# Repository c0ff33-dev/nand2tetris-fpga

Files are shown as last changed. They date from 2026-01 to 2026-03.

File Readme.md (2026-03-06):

# nand2tetris-fpga (v4.0.1)

## Disclaimer

This is both a complete implementation & fork of Michael Schröder's [course](https://gitlab.com/x653/nand2tetris-fpga). I have made my own revisions, extensions and corrections to:

* Update the code for modern tooling.
* Update virtually all of the documentation for readability, accuracy & completeness.
* Update the architecture to support current hardware revisions of the relevant boards.
* Restore ABI/API compatibility with VGA & PS/2 support in the [classic](./09_More_Fun_to_Go/) HACK implementation.
* Replace the original tools with a more sophisticated & optimized Jack compiler toolchain.

Please see [Changelog.md](./Changelog.md) for details.

***

> _Wouldn't it be nice to make Hack or Jack also run on some "real platform" made from some "real stuff"?_
> 
> Noam Nisan and Shimon Schocken

This project is about building HACK on real hardware as proposed in Chapter 13 of the course [nand2tetris](https://www.nand2tetris.org/) using only FOSS, free and open source hardware and software.

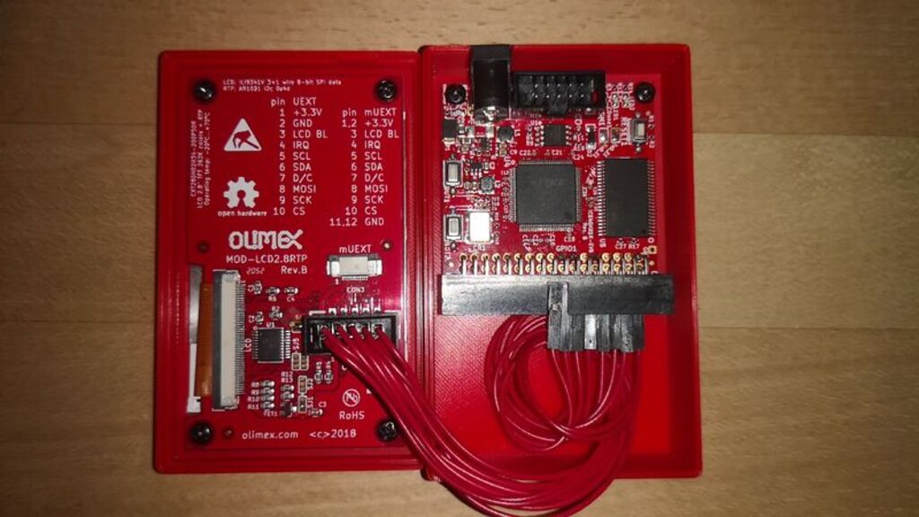
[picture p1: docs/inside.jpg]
 

Our final implementation of `HACK` will have the following specs:

* Original CPU/ALU design of `HACK` from nand2tetris.

* Implemented on `iCE40HX1K-EVB` from Olimex.

* Clocked at 25 MHz.

* BRAM 3584 x 16 bit (R0-R15/static/stack/heap).

* SRAM 64K x 16 bit (instruction memory).

* Bootloader boots `HACK` code from flash ROM into SRAM.

* 2.8 inch color `LCD` with 320x240 pixel.

* Resistive Touch Panel (`RTP`) support.

* Powerful enough to run Tetris!
  
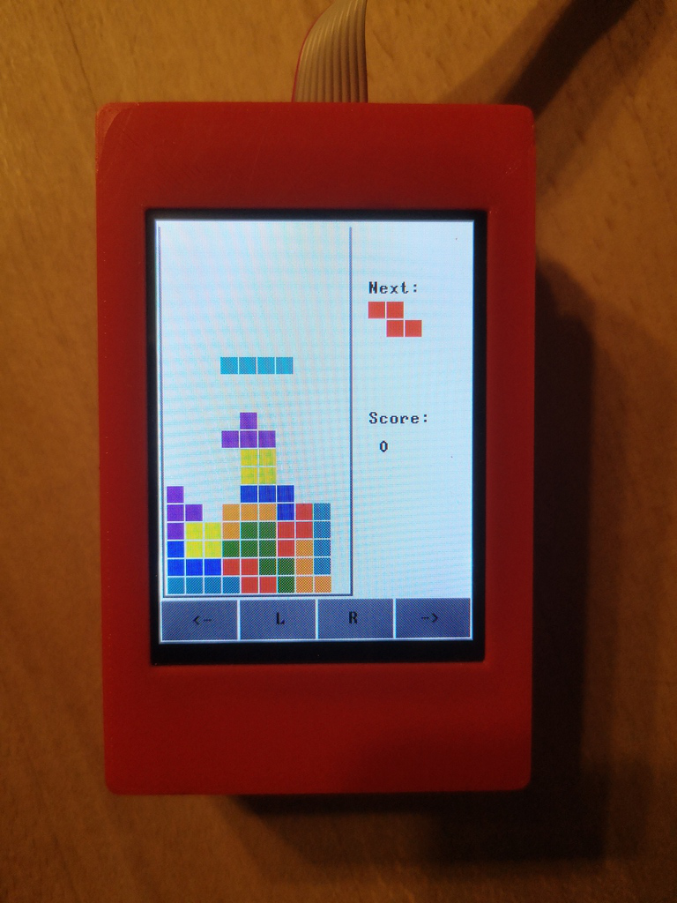
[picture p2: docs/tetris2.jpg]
  

***

## Roadmap

In every project folder you find a file `Readme.md` containing specifications and implementation details.

> _This is your last chance. After this, there is no turning back. You take the blue pill - the story ends, you wake up in your bed and believe whatever you want to believe. You take the red pill - you stay in Wonderland and I show you how deep the rabbit-hole goes._
> 
> Morpheus

### [00 Prerequisites](00_Prerequisites)

Get the hardware and install the tools.

### [01 Boolean Logic](01_Boolean_Logic)

Start with a simple `Nand` gate and build the logic chips: `Not`, `Buffer`, `And`, `Or`, `Xor`, `Mux`, `DMux`, and their multi-bit versions `Not16`, `Buffer16`, `And16`, `Or16`, `Mux16`, `Or8Way`, `Mux4Way16`, `Mux8Way16`, `DMux4Way` and `DMux8Way`.

### [02 Boolean Arithmetic](02_Boolean_Arithmetic)

Implement `HalfAdder`, `FullAdder`, `Add16`, `Inc16` and the `ALU`.

### [03 Sequential Logic](03_Sequential_Logic)

Build sequential chips `Bit` , `Register` and `PC` that make use of the Data Flip Flop (`DFF`) to store the state. `DFF` is a Verilog primitive so it will not necessary to implement it. The memory chips `RAM512` and `RAM3584` are based on the BRAM primitive `RAM256`, which uses Block RAM (BRAM) structures integrated in `iCE40HX1K`. `BitShift9R` and `BitShift8L` are new chips not explained in the original nand2tetris course. They serve to connect `HACK` to different I/O devices which are connected using a serial protocol where data is transmitted bitwise.

### [04 Machine Language](04_Machine_Language)

Write two little machine language programms to run on `HACK`. The first program `leds.asm` will test I/O capability of `HACK`. Every time the user presses the buttons `BUT1/2` on the `iCE40HX1K-EVB` board  the `LED` will change accordingly. With the second program `mult.asm` we will calculate the product of two numbers to test the arithmetic capabilities of the `CPU`/`ALU`.

### [05 Computer Architecture](05_Computer_Architecture)

Build `HACK` computer system consisting of the chips `CPU`, `Memory`, `Clock25_Reset20`, RAM and `ROM`. `ROM` uses a BRAM structure (512 bytes / 256 words) of `iCE40HX1K` and can be considered primitive. It can be preloaded with the instructions of the assembler programs implemented in `04_Machine_Language` .

### [06 I/O Devices](06_IO_Devices)

We will expand `HACK` computer platform by adding chips to handle communication to I/O devices, which we connect to `HACK`.

* `UART` communicates with 115200 baud 8N1 to computer.
* `SPI` reads the 2MB flash memory on `iCE40HX1K-EVB`.
* `SRAM` writes data to the external SRAM chip.
* `GO` enables booting Jack OS software.
* `LCD` connects a little color screen with 320x240 resolution.
* `RTP` connects the touch panel.

### [07 Operating System](07_Operating_System)

Implement the operating system Jack OS, written in the high level language Jack consisting of the classes `GPIO.jack`, `UART.jack`, `Memory.jack`, `Math.jack`, `Array.jack`, `String.jack`, `Screen.jack`, `Output.jack`, `Touch.jack` and `Sys.jack`

Finally you can compile and run Tetris!

### [08 3D Printer](08_3D_Printer)

We provide construction files to print a little case and development jig for your `HACK` computer with a 3D printer.

### [09 More Fun to Go](09_More_Fun_to_Go)

A classic `HACK` implementation which adds `PS/2` & `VGA` support via `iCE40-IO` for the Jack `Keyboard` and `Screen` interfaces.

## Credits

* Michael Schröder (mi.schroeder@netcologne.de), the original author of this course. Without them first demonstrating the art of the possible I am unlikely to have ever started.

* Noam Nisan and Shimon Schocken, "The Elements of Computing Systems", MIT Press. Visit [nand2tetris](https://nand2tetris.org) and learn to build a modern general purpose computer system from first principles.

* [Olimex Ltd](https://www.olimex.com/): Buy your hardware from the Company with highest number of registered OSHW projects :)

* Wolf Clifford: The master of open source FPGA with iCE40 and [Project IceStorm](http://www.clifford.at/icestorm/).

* Jesús Arroyo Torrens, Juan González (Obijuan): Open source ecosystem for open FPGA boards [APIO](https://github.com/FPGAwars/apio).

* Juan González-Gomez (Obijuan): Lern verilog with [open-fpga-verilog-tutorial](https://github.com/Obijuan/open-fpga-verilog-tutorial/).

* Icons made by <a href="https://www.flaticon.com/free-icon/cpu_483131?term=cpu&page=3&position=86" title="Those Icons">Those Icons</a> from <a href="https://www.flaticon.com/" title="Flaticon"> www.flaticon.com</a>

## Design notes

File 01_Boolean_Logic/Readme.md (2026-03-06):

# 01 Boolean Logic

The hardware part of the project `nand2tetris-fpga` is implemented in Verilog, a Hardware Description Language similar to the HDL used in the original nand2tetris course. There is no need to learn much Verilog, as you can easily translate all your HDL files into Verilog following the given example for `Xor`.

**Note:** The following modules are considered primitive and thus there is no need to implement them.

| Module | Description |
| --- | --- |
| `Nand.v` | Nand-gate. Basic building block for combinatorial logic |
| `DFF.v` | Data Flip Flop. Basic building block for sequential logic |
| `RAM256.v` | Uses BRAM of iCE40 |
| `ROM.v` | Uses BRAM of iCE40 preloaded with `HACK` code at startup |
| `InOut.v`  | Tristate buffer, used to connect to the bidirectional bus of SRAM |

***

## Example Xor

### Xor.hdl

Yout implementation of `Xor` in HDL (nand2tetris) should look something like:

```
// This file is part of www.nand2tetris.org
// and the book "The Elements of Computing Systems"
// by Nisan and Schocken, MIT Press.
// File name: projects/01/Xor.hdl

/** 
* Xor (exclusive or) gate:
* If a<>b out=1 else out=0.
*/

CHIP Xor {
    IN a, b;
    OUT out;

    PARTS:
    Not(in=a, out=nota);
    Not(in=b, out=notb);
    And(a=a, b=notb, out=w1);
    And(a=nota, b=b, out=w2);
    Or(a=w1, b=w2, out=out);
}
```

### Xor.v

`Xor.hdl` can easily be translated into `Xor.v` (Verilog):

```
/** 
* Xor (exclusive or) gate:
* If a<>b out=1 else out=0.
*/

module Xor(
    input a,
    input b,
    output out
);
    wire nota;        // new wire must be declared (as wire)
    wire notb;
    Not NOT1(.in(a), .out(nota)); // every chip has an instance name (NOT1)
    Not NOT2(.in(b), .out(notb)); // this chip is named NOT2

    wire w1;
    wire w2;
    And AND1(.a(a),.b(notb),.out(w1));
    And AND2(.a(nota),.b(b),.out(w2));

    Or OR(.a(w1),.b(w2),.out(out));
```

### Simulation

For every chip wie provide a test folder e.g. `05_Xor`, in which you find a so called test bench (`Xor_tb.v`). To run the test bench cd into the test directory and run apio:

```sh
$ cd 05_Xor
$ apio clean        (used to remove older implementation from cache)
$ apio sim
```

**Attention:** All used chips used in the Verilog code must be already implemented and included in the `Include.v` file.

The test bench will produce a graphical represantation `Xor.gtkw` of all signal lines, which can be viewed with gtkwave.



You can see four sections:

* `IN`: the input signals (generated by the test bench)
* `OUT`: the output signals (generated by YOUR chip implementation)
* `CMP`: the output signals (generated by the test bench)
* `Test`:  the fail signal. Goes high, when the test fails.

Your chip passes the test, when `out=out_cmp` and `fail=0` over the whole test time.

### iCE40HX1K.pcf

To upload the chip `Xor` onto your FPGA board `iCE40HX1K-EVB` you need two additional files: `top.v` and  `iCE40HX1K.pcf` (physical constraints file). The pyhiscal constraints file assigns every io-signal wire of the top level module `top.v` to physical pins of the FPGA chip `iCE40HX1K`. Pin numbering can be checked by consulting the schematic [iCE40HX1K-EVB](../docs/iCE40HX1K-EVB_Rev_B.pdf) in `docs/iCE40HX1K-EVB_Rev_B.pdf`.

```
# physical constraints file
# assign io-pins to pin numbering of iCE40HX1K on Olimex board iCE40HX1K-EVB
# compare to the schematic of the board and the datasheet of FPGA

set_io BUT1 41    # BUT1
set_io BUT2 42    # BUT2

set_io LED1 40    # LED1
set_io LED2 51    # LED2
```

* Now you can build and upload  the chip `Xor` to `iCE40HX1K-EVB` with:
  
```sh
$ apio clean
$ apio build
$ apio upload
```

* Press buttons `BUT1/2` and see the result of your `Xor` chip on `LED1`.

**Attention:** Due to pull up resistors at the buttons, the signals appear inverted:

| Pin | Function |
| --- | --- |
| `LED1/2` | =0 `LED` is off, =1 `LED` is on |
| `BUT1/2` | =0 button is pressed down, =1 button is released up |

Chips with no more than two input/output signals can be uploaded and tested on real hardware: `Nand`, `Not`, `Buffer`, `And`, `Or`, `Xor` and `DMux`.

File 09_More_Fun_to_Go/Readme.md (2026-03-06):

# 09 More Fun to Go!

In this section we will pivot back to a more classic `HACK` implementation using the `Keyboard` and `Screen` interfaces for I/O as described in the original nand2tetris spec. This will involve implementing `PS/2` and `VGA` controllers respectively to connect to a compatible keyboard and monitor. If still using the original `olimexino-32u4` + `iCE40HX1K-EVB` setup it can be expanded with `iCE40-IO` for `PS/2` and `VGA` ports and that will be the assumed setup in this implementation. 

Some changes will be needed to support writing pixel data to VRAM which was previously off loaded to `MOD-LCD2.8RTP` in the prior implementation, this board and the corresponding `LCD`/`RTP` controllers/drivers are no longer used.

If a part/class/test from previous `HACK` & Jack OS implementation could be carried forward then it is imported as is.

The [GateMateA1-EVB](https://www.olimex.com/Products/FPGA/GateMate/GateMateA1-EVB) board by Olimex could also be used here as seen in Michael Schröder's [hack-fpga](https://gitlab.com/x653/hack-fpga) project which is roughly comparable in cost to the sum of the parts described above but with far more FPGA resources. If you are seriously looking at doing a project like this yourself I would probably start there next time, there are significant constraints to `iCE40HX1K-EVB` which are abstracted away in more capable boards.

For keyboard I was using Adafruit's 60% hybrid USB and PS/2 [Keyboard](https://adafru.it/857) but anything with `PS/2` (directly or as fallback) should work. I happened to have an old monitor that will had a `VGA` port (sometimes also referred to as `D-sub` or `DE-15` port) but don't have any modern recommendations for that one.

These other/similar projects may be of interest for research purposes or board alternatives:

* https://gitlab.com/x653/hack-fpga
* https://github.com/giuseros/nand2tetris
* https://github.com/gunnerson/hack-fpga

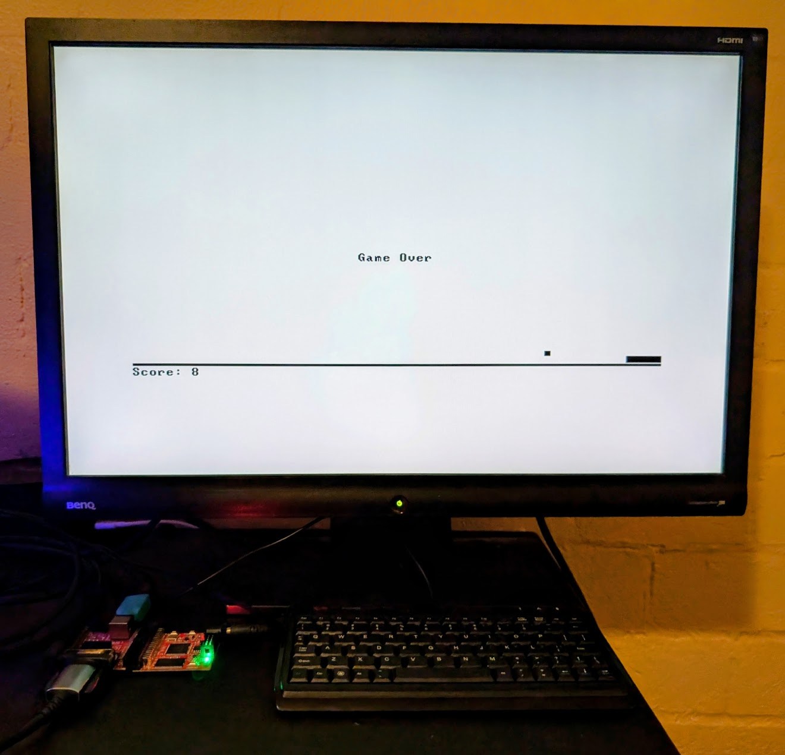
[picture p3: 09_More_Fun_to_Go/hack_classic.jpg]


## Major Changes

- Added `PS/2` and `VGA` & keyboard controllers.
  - A dedicated power supply must be used for the `PS/2` receiver to function correctly which requires 5v. If not required then powering the system with 3.3v over UEXT (i.e. via `olimexino-32u4` from USB power or otherwise) is still fine.
- Removed the `UartTX/RX`, `LCD` and `RTP` parts.
  - The `TX` pin for `olimexino-32u4` must not be set to `Output` in the sketch due to an electrical conflict with the `PS/2` receiver which indirectly connects to the same pin in shared fabric of `iCE40HX1K-EVB`.
  - If using jumper cables instead of a ribbon cable for UEXT simply disconnecting the `UART` lines should do the trick.
- The second 64KB page of `SRAM` memory is now used for heap & VRAM memory, the first `SRAM` page remains reserved for Jack application code.
  - All of the remaining `BRAM` memory can be used for stack storage.
- `SRAM_A/D` now supports multiple updates per cycle to support above: most updates are performed during `clk negedge` and expressed to CPU when it updates in `clk posedge` as normal.
  - This is a complex architectural change with significant performance implications, if you can get a board with dual port RAM to parallelize the VRAM reads I would strongly recommend it.
  - Because all these accesses to `SRAM` have to happen procedurally the `CPU` needs to be slowed down from 25 MHz to 6.25 MHz for there to be enough time to process everything, mainly allowing for signal propogation on the `SRAM` bus and the read/write cycle of `SRAM` itself.
- Restored all Jack classes & APIs to original nand2tetris spec where possible, some small tweaks exist to fit current architecture.

## Upload Bitstream

Build bootloader, copy into revised HACK directory & upload it (separately from remaining application code):

```sh
$ cd ~/src/nand2tetris-fpga/06_IO_Devices/05_GO && make && cp ../00_HACK/ROM.hack ../../09_More_Fun_to_Go/00_HACK && cd ../../09_More_Fun_to_Go/00_HACK && apio clean && apio upload
```

## Upload Application

See [Appendix.md](../00_Prerequisites/Appendix.md) for complete list of Jack tests.

```sh
$ cd ~/src/nand2tetris-fpga/09_More_Fun_to_Go/03_Pong && make && make upload
```

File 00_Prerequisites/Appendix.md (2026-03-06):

# Appendix

Cliff notes for environment setup/installation.

### Notes

* `iceprogduino` is targeting POSIX dependencies not available on Windows.
* `winiceprogduino` does not support writing to offsets.
* `usbipd` is needed for WSL as the COM passthrough doesn't support the necessary IOCTLs.

## Install dependencies

### Python 3.11/12

```sh
$ sudo apt update
$ sudo apt install software-properties-common
$ sudo add-apt-repository ppa:deadsnakes/ppa
$ sudo apt install python3.11 python3.11-venv python3.12 python3.12-venv
```

### git and repos

```sh
$ sudo apt install git
$ mkdir src && cd src
$ git clone git@github.com:c0ff33-dev/nand2tetris-fpga.git
```

### Install apio + dependencies

```sh
$ cd nand2tetris-fpga
$ python3.11 -m venv .venv
$ source .venv/bin/activate
$ python -m pip install apio
$ apio install oss-cad-suite
$ apio install examples

$ sudo apt install gtkwave
$ sudo apt install tio # serial client
$ sudo apt install xvfb # not needed on wsl
```

### Build + install the programmer

```sh
$ cd ../iCE40HX1K-EVB/programmer/iceprogduino
$ sudo apt install build-essential unzip
$ make
$ sudo make install
```

### Arduino dependencies

```sh
$ cd ~ && curl -fsSL https://raw.githubusercontent.com/arduino/arduino-cli/master/install.sh | sh
$ sudo ln -sf ~/bin/arduino-cli /usr/local/bin/arduino-cli
$ arduino-cli core install arduino:avr
$ arduino-cli lib install "Adafruit GFX Library@1.2.3"
$ wget https://github.com/Marzogh/SPIMemory/archive/refs/tags/v2.2.0.zip -O SPIMemory-2.2.0.zip
$ unzip SPIMemory-2.2.0.zip -d ~/Arduino/libraries/
```

### WSL: Install usbipd to bridge usb

```sh
$ winget install --interactive --exact dorssel.usbipd-win # restart shell
$ usbipd list
$ usbipd bind --busid 1-3 # USB Serial Device (COM3)
$ usbipd attach --wsl --busid 1-3
$ lsusb # wsl: Arduino SA Leonardo (CDC ACM, HID)
$ usbipd detach --wsl --busid 1-3
$ usbipd unbind --all
```

## Prepare board & development environment

### Enable write perms on the serial port

```sh
$ sudo chmod a+rw /dev/ttyACM0
```

### Flash the programmer

If having trouble with disconnects here in WSL may need to use a full VM with USB passthrough:

```sh
$ arduino-cli compile --upload -p /dev/ttyACM0 --fqbn arduino:avr:leonardo "/home/veris/src/nand2tetris-fpga/tools/olimexino-32u4/iceprog"
$ arduino-cli compile --upload -p /dev/ttyACM0 --fqbn arduino:avr:leonardo /home/veris/src/MOD-LCD2.8RTP/SOFTWARE/Arduino/graphicstest_olimex_NS2009
```

### Upload test program

```sh
$ cd ~/src/nand2tetris-fpga
$ apio examples -d iCE40-HX1K-EVB/leds
$ cd iCE40-HX1K-EVB/leds
$ apio sim
$ apio build
$ apio upload
```

## Miscellaneous

### Useful VSC extensions

```
mshr-h.veriloghdl
throvn.nand2tetris
roman-lukash.nand2tetris-jack-language-server
```

### Check LC utilization & timing

```sh
$ apio clean && apio build --verbose-pnr > log.txt
$ grep -ie "ICESTORM_LC:  " log.txt
$ grep -ie "frequency" log.txt
```

## Testing & Validation

## Update compiler/translator/assembler binaries

```sh
cd ~/src/nand2tetris/interpreter && rm ./__pycache__/*.pyc && python3.12 -m compileall .
cp ~/src/nand2tetris/interpreter/__pycache__/tokenizer.cpython-312.pyc ~/src/nand2tetris-fpga/tools/JackCompiler/tokenizer.pyc
cp ~/src/nand2tetris/interpreter/__pycache__/analyzer.cpython-312.pyc ~/src/nand2tetris-fpga/tools/JackCompiler/analyzer.pyc
cp ~/src/nand2tetris/interpreter/__pycache__/compiler.cpython-312.pyc ~/src/nand2tetris-fpga/tools/JackCompiler/compiler.pyc
cp ~/src/nand2tetris/interpreter/__pycache__/translator.cpython-312.pyc ~/src/nand2tetris-fpga/tools/VMTranslator/translator.pyc
cp ~/src/nand2tetris/interpreter/__pycache__/assembler.cpython-312.pyc ~/src/nand2tetris-fpga/tools/Assembler/assembler.pyc
cd ~/src/nand2tetris-fpga
```

### Original HACK

Flash the "UART" sketch (from VM):

```sh
cd ~/src/nand2tetris-fpga/tools/olimexino-32u4/iceprog2 && sudo ln -sf ../src/iceprog_UART.ino iceprog2.ino
arduino-cli compile --upload -p /dev/ttyACM0 --fqbn arduino:avr:leonardo "/home/<user>/src/nand2tetris-fpga/tools/olimexino-32u4/iceprog2"
```

If using WSL, reattach the port:

```sh
usbipd attach --wsl --busid <busid>
```

Upload bootloader + bitstream:

```sh
$ source ~/src/nand2tetris-fpga/.venv/bin/activate
$ cd ~/src/nand2tetris-fpga/06_IO_Devices/05_GO && make && cd ../00_HACK && apio clean && apio upload
```

Jack tests:

```sh
$ cd ~/src/nand2tetris-fpga/07_Operating_System/01_GPIO_Test && make clean && make && cd ../00_HACK && apio clean && apio sim
$ cd ~/src/nand2tetris-fpga/07_Operating_System/01_GPIO_Test && make clean && make && make upload

# swap RTP for UART in 06_IO_Devices\HACK.v (LC budget) & reflash the hardware bitstream
# ensure olimexino is in bridge mode (green) when transmitting & regular (yellow) when programming
# for LEDs near USB port on olimexino, yellow = rx (from PC) & green = tx (from FPGA)
$ cd ~/src/nand2tetris-fpga/07_Operating_System/02_UART_Test && make clean && make && cd ../00_HACK && apio clean && apio sim
$ cd ~/src/nand2tetris-fpga/07_Operating_System/02_UART_Test && make clean && make && make upload && tio /dev/ttyACM0
$ cd ~/src/nand2tetris-fpga/07_Operating_System/03_Sys_Test && make clean && make && make upload

$ cd ~/src/nand2tetris-fpga/07_Operating_System/04_Memory_Test && make clean && make && cd ../00_HACK && apio clean && apio sim
$ cd ~/src/nand2tetris-fpga/07_Operating_System/05_Array_Test && make clean && make && cd ../00_HACK && apio clean && apio sim
$ cd ~/src/nand2tetris-fpga/07_Operating_System/06_Math_Test && make clean && make && cd ../00_HACK && apio clean && apio sim
$ cd ~/src/nand2tetris-fpga/07_Operating_System/07_String_Test && make clean && make && cd ../00_HACK && apio clean && apio sim

# ctrl+t, l to clear tio output & reset FPGA (not olimexino)
$ cd ~/src/nand2tetris-fpga/07_Operating_System/07_String_Test && make clean && make && make upload && tio /dev/ttyACM0
$ cd ~/src/nand2tetris-fpga/07_Operating_System/08_StdIO_Test && make clean && make && make upload && tio /dev/ttyACM0
$ cd ~/src/nand2tetris-fpga/07_Operating_System/09_Screen_Test && make clean && make && cd ../00_HACK && apio clean && apio sim
$ cd ~/src/nand2tetris-fpga/07_Operating_System/09_Screen_Test && make clean && make && make upload
$ cd ~/src/nand2tetris-fpga/07_Operating_System/10_Output_Test && make clean && make && make upload

# swap UART for RTP in 06_IO_Devices\HACK.v & re-flash the hardware bitstream!

# sim only available for AR1021 emulation only: see 06_IO_Devices/Readme.md for full list of refs
# if disabling Screen/ScreenExt/Output.init() for speed need to also disable the Output.print*() calls in test!
# $ cd ~/src/nand2tetris-fpga/07_Operating_System/11_Touch_Test && make clean && make && cd ../00_HACK && apio clean && apio sim

$ cd ~/src/nand2tetris-fpga/07_Operating_System/11_Touch_Test && make clean && make && make upload
$ cd ~/src/nand2tetris-fpga/07_Operating_System/12_Tetris && make clean && make && make upload
```

### Classic HACK

Flash the "NoUART" sketch (from VM):

```sh
cd ~/src/nand2tetris-fpga/tools/olimexino-32u4/iceprog2 && sudo ln -sf ../src/iceprog_NoUART.ino iceprog2.ino
arduino-cli compile --upload -p /dev/ttyACM0 --fqbn arduino:avr:leonardo "/home/<user>/src/nand2tetris-fpga/tools/olimexino-32u4/iceprog2"
```

If using WSL, reattach the port:

```sh
usbipd attach --wsl --busid <busid>
```

Upload bootloader + bitstream:

```sh
$ source ~/src/nand2tetris-fpga/.venv/bin/activate
$ cd ~/src/nand2tetris-fpga/06_IO_Devices/05_GO && make && cp ../00_HACK/ROM.hack ../../09_More_Fun_to_Go/00_HACK && cd ../../09_More_Fun_to_Go/00_HACK && apio clean && apio upload
```

Jack tests:

```sh
# Application code can be flashed straight to offset 0x10000 as before
# 07_Operating_System tests use original Sys.jack so runs at 1/4 timing for Sys.wait() calls (i.e. slower)
$ cd ~/src/nand2tetris-fpga/07_Operating_System/01_GPIO_Test && make clean && make && make upload
$ cd ~/src/nand2tetris-fpga/07_Operating_System/03_Sys_Test && make clean && make && make upload

# HACK_OS sims: can uncomment additional debug registers in HACK where necessary
# OS tests are too large to be sim'd without using a larger/non-uploadable ROM part (i.e. as done in original 07_Operating_System)
# some need a longer simulation time up to ~1.25 million ticks to complete on the slower CPU timing for the full program
$ cd ~/src/nand2tetris-fpga/07_Operating_System/04_Memory_Test && make clean && make && cp ../00_HACK/ROM.hack ../../09_More_Fun_to_Go/00_HACK_OS && cd ../../09_More_Fun_to_Go/00_HACK_OS && apio clean && apio sim
$ cd ~/src/nand2tetris-fpga/07_Operating_System/05_Array_Test && make clean && make && cp ../00_HACK/ROM.hack ../../09_More_Fun_to_Go/00_HACK_OS && cd ../../09_More_Fun_to_Go/00_HACK_OS && apio clean && apio sim
$ cd ~/src/nand2tetris-fpga/07_Operating_System/06_Math_Test && make clean && make && cp ../00_HACK/ROM.hack ../../09_More_Fun_to_Go/00_HACK_OS && cd ../../09_More_Fun_to_Go/00_HACK_OS && apio clean && apio sim

# VGA tests
$ cd ~/src/nand2tetris-fpga/09_More_Fun_to_Go/02_Operating_System/07_String_Test && make clean && make && make upload
$ cd ~/src/nand2tetris-fpga/09_More_Fun_to_Go/02_Operating_System/09_Screen_Test && make clean && make && make upload
$ cd ~/src/nand2tetris-fpga/09_More_Fun_to_Go/02_Operating_System/10_Output_Test && make clean && make && make upload

# Keyboard tests: dedicated power supply required for PS/2 (5v)
$ cd ~/src/nand2tetris-fpga/09_More_Fun_to_Go/02_Operating_System/14_Keyboard_Test && make clean && make && make upload
$ cd ~/src/nand2tetris-fpga/09_More_Fun_to_Go/03_Pong && make clean && make && make upload
```

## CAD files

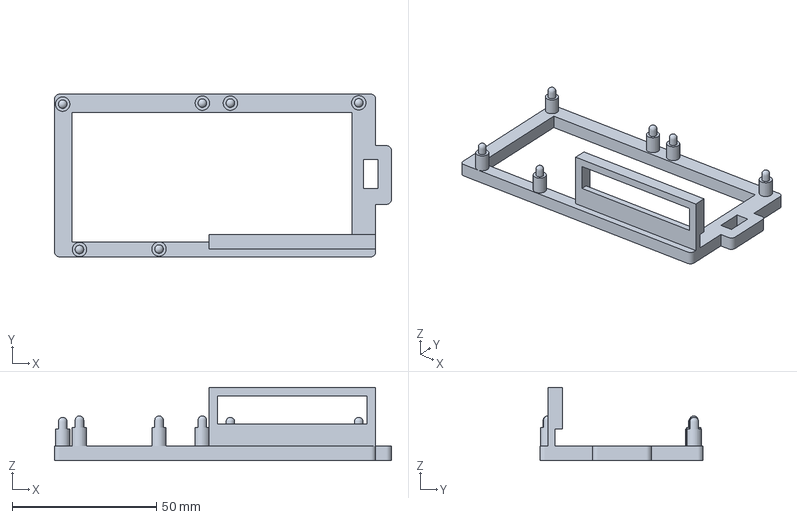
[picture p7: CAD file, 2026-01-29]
08_3D_Printer/00_Dev_Jig/Cura/FPGA_Arduino_Holder_PLA.3mf
116.7 x 56.4 x 25.4 mm

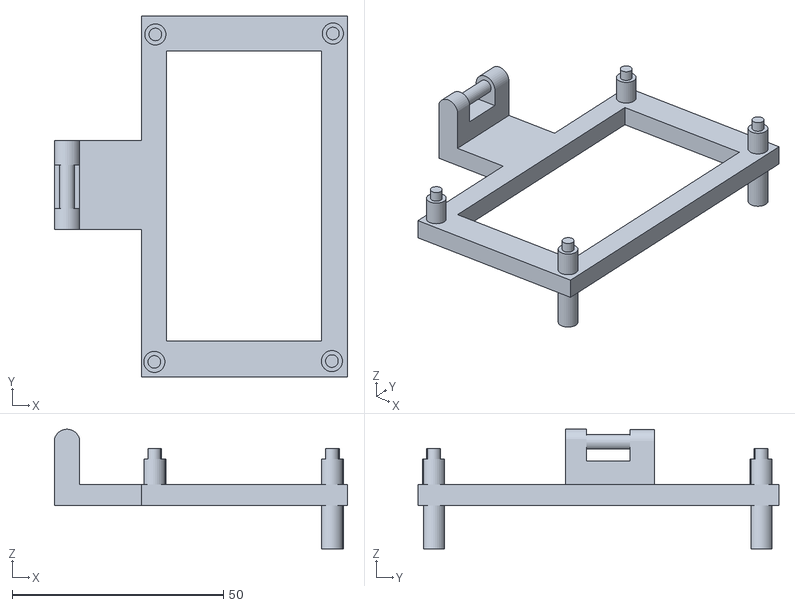
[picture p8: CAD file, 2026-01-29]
08_3D_Printer/00_Dev_Jig/STL/LCD_Holder.stl
69.3 x 85.4 x 28.3

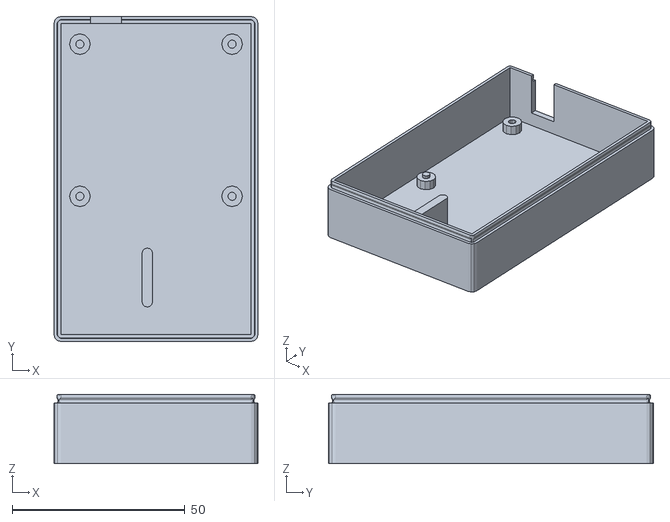
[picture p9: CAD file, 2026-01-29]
08_3D_Printer/01_Display_Case/rear_HX1K-Cube.stl
59.0 x 94.0 x 20.0

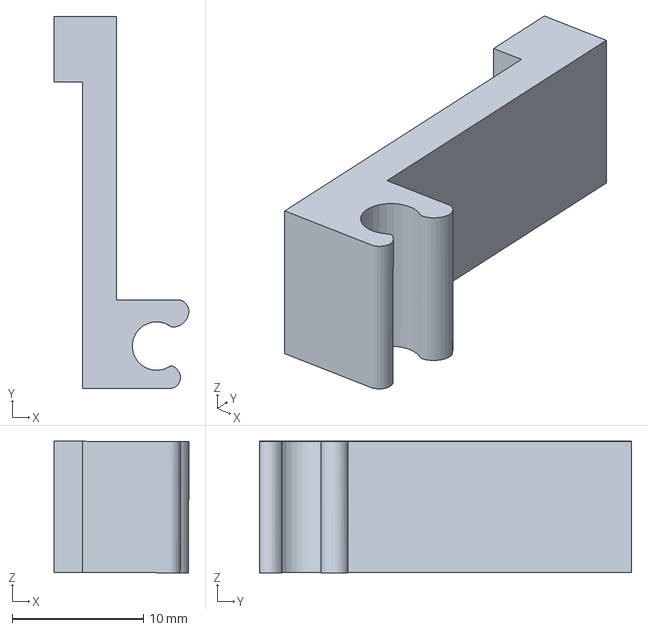
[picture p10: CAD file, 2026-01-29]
08_3D_Printer/00_Dev_Jig/Cura/Clip_Peg_PLA.3mf
10.3 x 28.3 x 10.0 mm

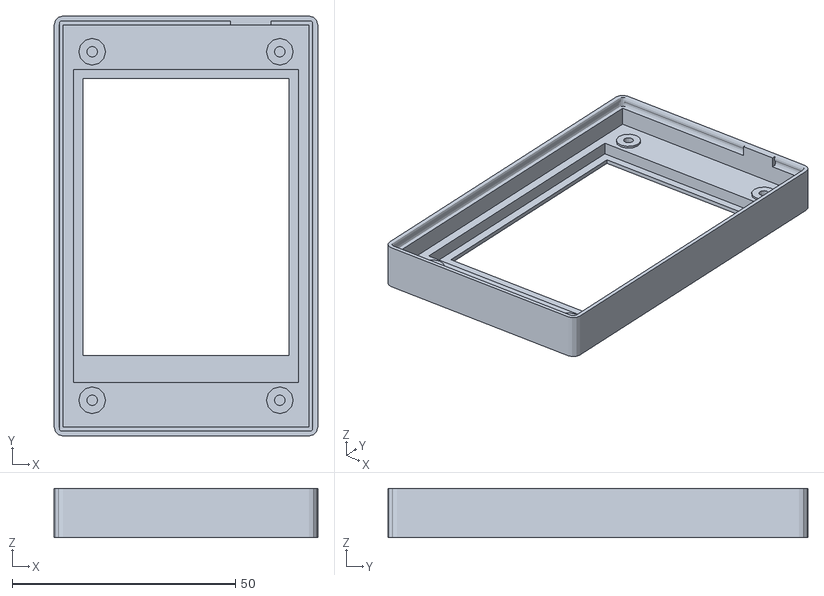
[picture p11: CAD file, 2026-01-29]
08_3D_Printer/01_Display_Case/front_HX1K-Cube.stl
59.0 x 94.0 x 11.0

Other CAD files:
08_3D_Printer/00_Dev_Jig/STL/Clip_Peg.stl
08_3D_Printer/00_Dev_Jig/Cura/LCD_Holder_PLA.3mf
08_3D_Printer/00_Dev_Jig/STL/FPGA_Arduino_Holder.stl
08_3D_Printer/00_Dev_Jig/Fusion/FPGA_Jig.f3d
08_3D_Printer/01_Display_Case/front_HX1K.blend
08_3D_Printer/01_Display_Case/nothing.blend
08_3D_Printer/01_Display_Case/rear_HX1K.blend

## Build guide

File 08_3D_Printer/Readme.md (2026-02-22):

# 08 3D Printer

* `00_Dev_Jig` contains a basic jig to clip the `olimexino-32u4`, `iCE40HX1K-EVB` & `MOD-LCD2.8RTP` and boards into place for easy access during development, the latter can be laid flat or rotated vertically for a "billboard" style effect. The boards are so light the pressure from the various cables tends to splay them out in random directions otherwise but this is completely optional.
* `01_Display_Case` similarly contains the original files for a display case/enclosure without the `olimexino-32u4` if you prefer a more complete/finished look.

**Note:** If continuing to [09 More Fun to Go](../09_More_Fun_to_Go/Readme.md) we don't currently have a design to support the additional `iCE40-IO` board.

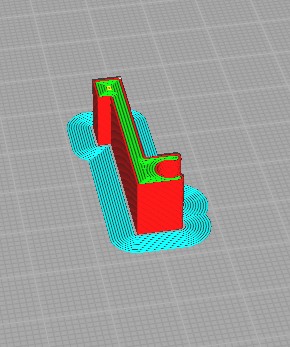
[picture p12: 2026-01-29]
08_3D_Printer/00_Dev_Jig/Images/03_Clip_Peg_Cura.jpg

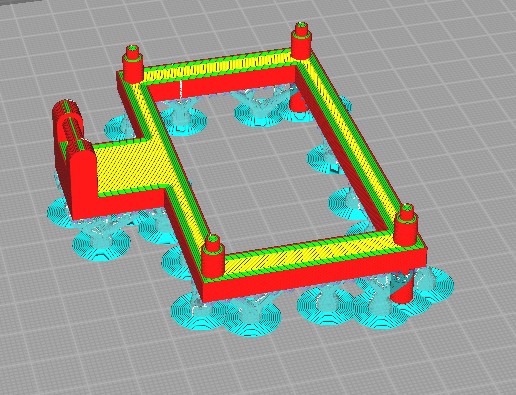
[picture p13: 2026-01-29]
08_3D_Printer/00_Dev_Jig/Images/02_LCD_Cura.jpg

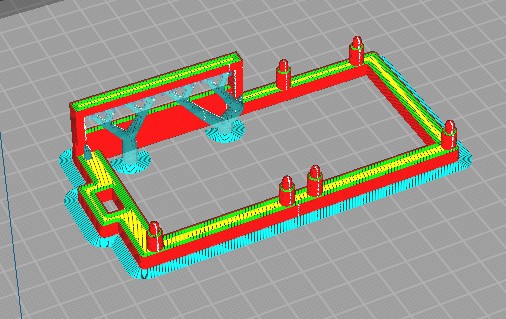
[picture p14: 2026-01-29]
08_3D_Printer/00_Dev_Jig/Images/01_FPGA_Arduino_Cura.jpg

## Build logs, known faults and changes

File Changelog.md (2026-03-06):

# Version v4.0.1: Minor updates

* Minor documentation edits.

# Version v4.0.0: Update compiler toolchain

* Compiler toolchain has now been totally replaced with the one from the original [nand2tetris](https://github.com/c0ff33-dev/nand2tetris) project @ **v1.0.0**.
  * See [CHANGELOG.md](https://github.com/c0ff33-dev/nand2tetris/blob/main/CHANGELOG.md) for a breakdown of major features.
  * Although great pains have been taken to ensure compatibility updating the compiler is always a risky operation, there have been no other functional updates so consider reverting to the previous release if necessary.
* Removed unused/unmaintained tools & vim profiles.
* Continued refining documentation.

# Version v3.1.1-3.1.2: Minor updates

* VRAM is now initialized during power on in hardware instead of software.
* Restored missing `GPIO.jack` in Pong.
* Continued refining documentation.

# Version v3.1: Classic HACK

* Major update in [09 More Fun to Go](./09_More_Fun_to_Go/Readme.md) which forks an additional `HACK` variant with `VGA` and `PS/2` support, adds new test bench emulators & where feasible imports original nand2tetris Jack libraries to restore API compatibility.
* Added additional check for heap overflow in `Memory.jack`.
* Continued refining documentation.

# Version v3.0: Fork

### Base content changes

* Added many Verilog & `apio.ini` fixes for modern yosys.
* Added several test fixes/enhancements & many documentation updates.
* Added syncronized read/write for BRAM/ROM/SRAM & tighter timing for `SPI` (2x faster).
  * Currently run mode for SRAM is still unsyncronized.
* Split `RTP` into `AR1021` + `NS2009` implementations.
  * Added documentation & test bench for the latter.
* Added logic to the `iceprogduino` sketch to filter UART traffic before `CDONE` signal is received.
* Restored functions that modified nand2tetris API signatures and nand2tetris copyright to Jack files.
* Split graphics API where original nand2tetris API is preserved in `Screen` while new functions were added to `ScreenExt`.
  * Renamed `writeData16()` to `writeRgbData()` in ScreenExt.
* Added new/updated datasheets.
* Added 3D printer files for development jig.
* Added `Appendix.md` with cliff notes for development environment setup.

### Implementation changes

* Added initial implementation for all parts/classes.
* Added `Util` module for homing miscellaneous helper functions.
* Added support for landscape orientation in `Output`.

# Version v2.0 (Pre-Fork)

## Update 04.08.2023

### Update tools to Python3.11

* `tools/Assembler/assembler.pyc`
* `tools/Jack/JackCompiler.pyc`
* `tools/Jack/VMTranslator.pyc`

### Fixes

* Corrected diagrams: `leds.png`, `mult.png`.

## Update 18.10.2022

### Fixes

* `Hack/CPU.v`: Replace `loadM` with `writeM`.
* Update diagrams.

### Update tools to Python3.10

* `tools/Assembler/assembler.pyc`
* `tools/Jack/JackCompiler.pyc`
* `tools/Jack/VMTranslator.pyc`

### Update Jack OS

* `Jack/UART.jack`: replace `init()` with `init(int addr)`

### Weird behaviour of iCE40HX8K-EVB

* `Hack/RAM.v`: replace `always @(negedge clk)` to `always @(posedge clk)`
* `Hack/DFF.v`: replace `always @(negedge clk)` to `always @(posedge clk)`
* `Hack/Clock.v`: 25 MHz

### iceprog: programmer.ino

* Set default to `bridge` mode (green LED on).

### Consistency

* `Hack/Reset.v`

### Boot from SPI

* `04_Hack-FLASH`

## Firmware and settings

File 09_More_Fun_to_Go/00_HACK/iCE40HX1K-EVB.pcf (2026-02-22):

# physical constraints file
# assign io-pins to pin numbering of iCE40HX1K on olimex board iCE40HX1K-EVB
# compare to the schematic of the board and the datasheet of FPGA

set_frequency CLK 25 # Clock frequency constraint (25 MHz)
set_io CLK 15        # SYSCLOCK 100 MHz

set_io BUT[0] 41    # BUT1
set_io BUT[1] 42    # BUT2

set_io LED[0] 40    # LED1
set_io LED[1] 51    # LED2

set_io SPI_SDO 45   # iCE40-SDO
set_io SPI_SDI 46   # iCE40-SDI
set_io SPI_SCK 48   # iCE40-SCK
set_io SPI_CSX 49   # iCE40-SS_B

set_io SRAM_ADDR[0] 79   # SA0
set_io SRAM_ADDR[1] 80   # SA1
set_io SRAM_ADDR[2] 81   # SA2
set_io SRAM_ADDR[3] 82   # SA3
set_io SRAM_ADDR[4] 83   # SA4
set_io SRAM_ADDR[5] 85   # SA5
set_io SRAM_ADDR[6] 86   # SA6
set_io SRAM_ADDR[7] 87   # SA7
set_io SRAM_ADDR[8] 89   # SA8
set_io SRAM_ADDR[9] 90   # SA9
set_io SRAM_ADDR[10] 91  # SA10
set_io SRAM_ADDR[11] 93  # SA11
set_io SRAM_ADDR[12] 94  # SA12
set_io SRAM_ADDR[13] 95  # SA13
set_io SRAM_ADDR[14] 96  # SA14
set_io SRAM_ADDR[15] 97  # SA15
set_io SRAM_ADDR[16] 99  # SA16
set_io SRAM_ADDR[17] 100 # SA17

set_io SRAM_CSX 78       # SRAM_#CS
set_io SRAM_OEX 74       # SRAM_#OE
set_io SRAM_WEX 73       # SRAM_#WE

set_io SRAM_DATA[0] 62   # SD0
set_io SRAM_DATA[1] 63   # SD1
set_io SRAM_DATA[2] 64   # SD2
set_io SRAM_DATA[3] 65   # SD3
set_io SRAM_DATA[4] 66   # SD4
set_io SRAM_DATA[5] 68   # SD5
set_io SRAM_DATA[6] 69   # SD6
set_io SRAM_DATA[7] 71   # SD7
set_io SRAM_DATA[8] 72   # SD8
set_io SRAM_DATA[9] 60   # SD9
set_io SRAM_DATA[10] 59  # SD10
set_io SRAM_DATA[11] 57  # SD11
set_io SRAM_DATA[12] 56  # SD12
set_io SRAM_DATA[13] 54  # SD13
set_io SRAM_DATA[14] 53  # SD14
set_io SRAM_DATA[15] 52  # SD15

set_io PS2_CLK 37  # PI02_9 TxD
set_io PS2_DATA 36 # PI02_8 RxD

set_io VGA_VS 34 # PI02_6 VGA_VSYNC
set_io VGA_HS 33 # PI02_7 VGA_HSYNC
set_io VGA_B[2] 30 # PI02_5 VGA_BLUE3
set_io VGA_B[1] 29 # PI02_4 VGA_BLUE2
set_io VGA_B[0] 28 # PI02_3 VGA_BLUE1
set_io VGA_G[2] 27 # PIO2_2 VGA_GREEN3
set_io VGA_G[1] 26 # PIO2_1 VGA_GREEN2
set_io VGA_G[0] 25 # PIO3_12B VGA_GREEN1
set_io VGA_R[2] 24 # PIO3_12A VGA_RED3
set_io VGA_R[1] 19 # PIO3_8B VGA_RED2
set_io VGA_R[0] 18 # PIO3_8A VGA_RED1
